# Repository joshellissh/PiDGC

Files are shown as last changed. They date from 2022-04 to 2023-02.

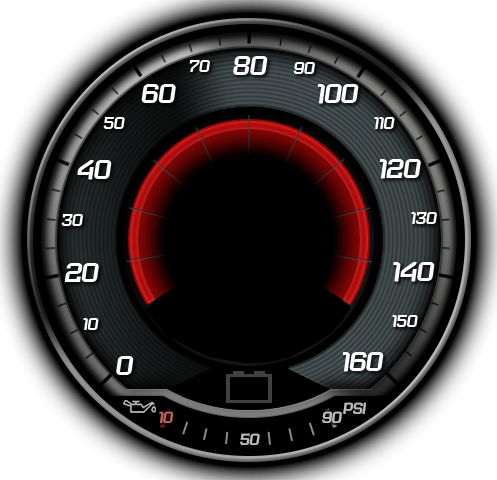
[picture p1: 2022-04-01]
source/display/images/right_gauge_bg_2.png

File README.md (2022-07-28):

# PiDGC v2
Raspberry Pi based Digital Gauge Cluster by Josh Ellis / josh@ellis.sh

**Please Note: This library is designed for the Raspberry Pi 3B, a custom built PCB, and a 1280x480 display. It
will look weird on other displays and won't function without those components.**

### Update Information
This repository is a total rewrite of the PiDGC codebase. The kotlin hardware interface has 
been removed, and all code is now in either the microcontroller (Teensy 4.1) or the Qt 
application running on the RPi. These changes were made to simplify the system and significantly 
shorten the boot time.

### Acknowledgements
In order to reduce the boot time significantly, this version of the gauge cluster uses [buildroot](https://buildroot.org/).
A fork of the [configuration](https://github.com/furkantokac/buildroot) made by [Furkan Tokaç](https://furkantokac.com/rpi3-fast-boot-less-than-2-seconds/) 
is the basis of this build, so many thanks for the reduced boot time go to him! Please go and check out his work, 
it's great.

### Software Steps
Since this is a buildroot build and no binaries are provided, you must build the image for the Raspberry Pi 3 yourself.
This isn't a complicated process, but does require either a Linux system or WSL2.

**These are high level steps only. If you have questions about how to do any step, please Google it.**

1. `cd` into the `buildroot` directory
2. `make pidgc_defconfig`
3. `make -j8`
4. `./build-rpi3-qt.sh`
5. Setup Qt Creator to use the qmake found in `buildroot/output/qt/qt-everywhere-src-*/aaaout/bin/qmake` and compile for the Raspberyr Pi 3.
6. Open `source/display` in Qt Creator and compile for RPi3.
7. Run `make -j8` again. This should pull in the `rpi3-display/display` binary and create the `sdcard.img` in `buildroot/output/images/sdcard.img`.
8. Burn the image file to a micro SD card.
9. All done!

### Custom PCB
The PCB was designed in EAGLE, and is located in `files/PiDGCv2-pcb`

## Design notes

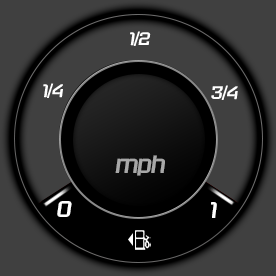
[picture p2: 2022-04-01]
source/display/images/right_gauge_fg.png

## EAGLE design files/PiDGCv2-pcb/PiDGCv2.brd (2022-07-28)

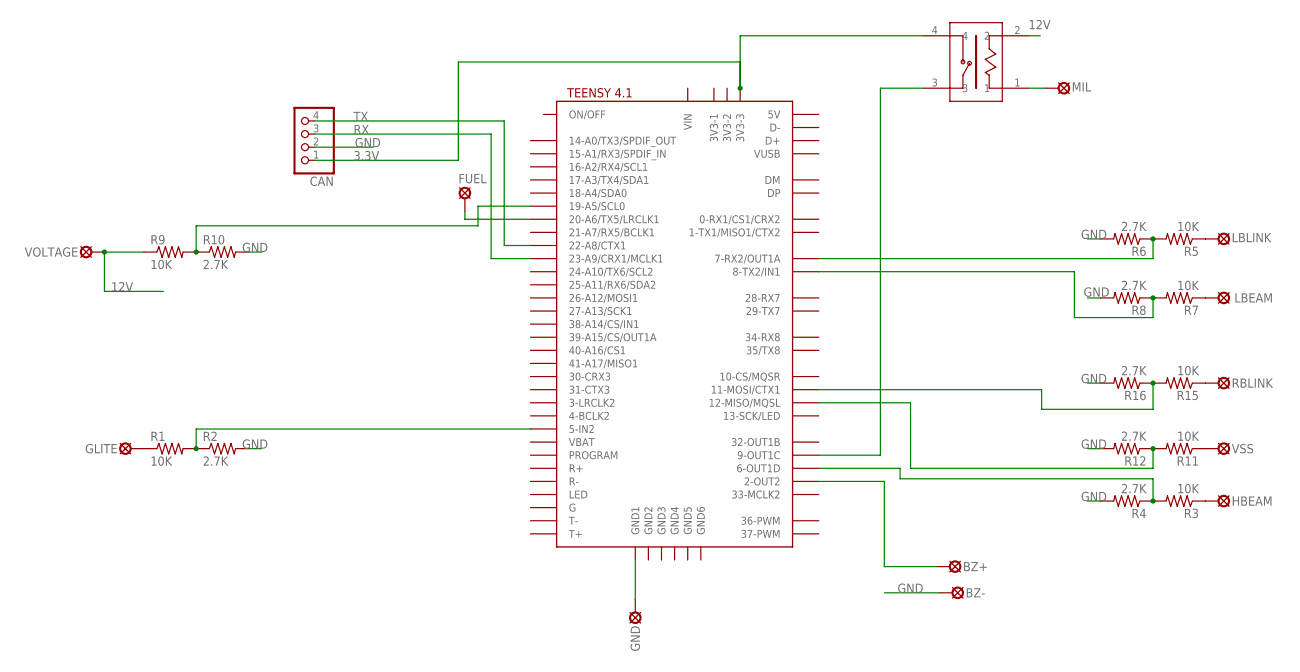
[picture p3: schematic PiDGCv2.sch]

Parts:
BZ+: LSP10
BZ-: LSP10
CAN: PINHD-1X4; 1X04
FUEL: LSP10
GLITE: LSP10
GND: LSP10
HBEAM: LSP10
LBEAM: LSP10
LBLINK: LSP10
MIL: LSP10
MIL_RELAY: BR-1050-VP; RELAY
R1, R3, R5, R7, R9, R11, R15: 10K; 0204/7
R2, R4, R6, R8, R10, R12, R16: 2.7K; 0204/7
RBLINK: LSP10
U$1: TEENSY41
VOLTAGE: LSP10
VSS: LSP10

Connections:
3.3V: CAN.1, MIL_RELAY.4, U$1.3V3-3
12V: MIL_RELAY.2, R9.1, VOLTAGE.MP; also elsewhere on the board
GND: BZ-.MP, CAN.2, GND.MP, R2.2, R4.2, R6.2, R8.2, R10.2, R12.2, R16.2, U$1.GND1
unnamed: R3.2, R4.1, U$1.6-OUT1D
unnamed: R1.2, R2.1, U$1.5-IN2
unnamed: GLITE.MP, R1.1
unnamed: HBEAM.MP, R3.1
unnamed: R5.2, R6.1, U$1.7-RX2/OUT1A
unnamed: LBLINK.MP, R5.1
unnamed: R7.2, R8.1, U$1.8-TX2/IN2 (8-TX2/IN1)
unnamed: LBEAM.MP, R7.1
unnamed: FUEL.MP, U$1.20-A6/TX5/LRCLK1
unnamed: R9.2, R10.1, U$1.19-A5/SCL0
unnamed: R11.2, R12.1, U$1.12-MISO/MQSL
unnamed: R11.1, VSS.MP
unnamed: R15.2, R16.1, U$1.11-MOSI/CTX1
unnamed: R15.1, RBLINK.MP
unnamed: MIL.MP, MIL_RELAY.1
unnamed: MIL_RELAY.3, U$1.9-OUT1C
unnamed: BZ+.MP, U$1.2-OUT2
RX: CAN.3, U$1.23-A9/CRX1/MCLK1
TX: CAN.4, U$1.22-A8/CTX1

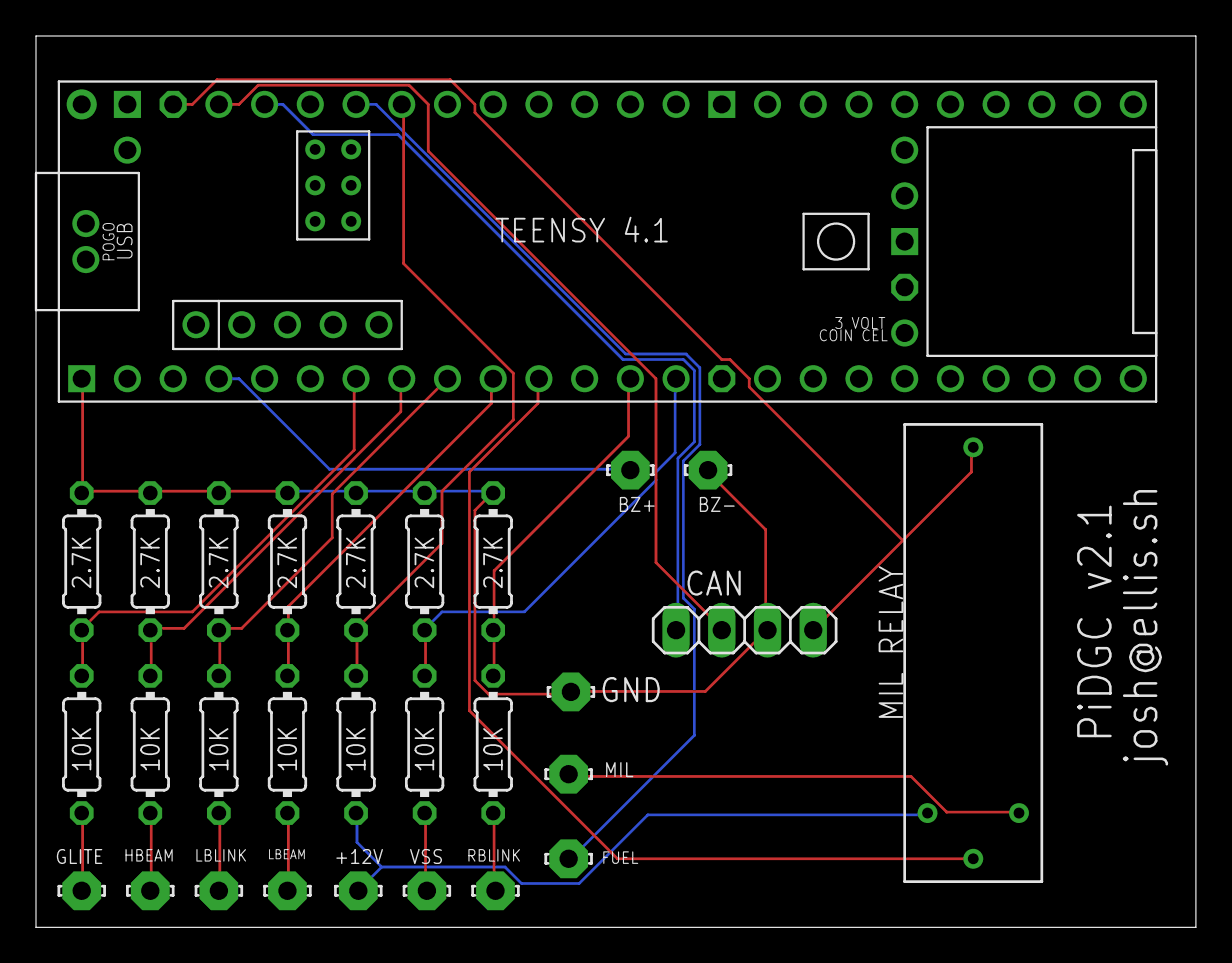
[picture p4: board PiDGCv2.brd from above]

Board: 2 copper layers, 64.4 x 49.5 mm, 29 parts (0 on the bottom side), 22 nets.

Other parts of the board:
+12V: LSP10

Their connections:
12V: +12V.MP; also elsewhere on the board

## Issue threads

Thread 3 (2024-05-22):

Stuck on make -j8 command

Hanifudin95, 2024-05-22:
hello josh, currently i am stuck on make -j8 command. What should i do mate

make -j8
>>>   Finalizing target directory
# Check files that are touched by more than one package
./support/scripts/check-uniq-files -t target /home/pi/PiDGC/buildroot/output/build/packages-file-list.txt
./support/scripts/check-uniq-files -t staging /home/pi/PiDGC/buildroot/output/build/packages-file-list-staging.txt
./support/scripts/check-uniq-files -t host /home/pi/PiDGC/buildroot/output/build/packages-file-list-host.txt
Warning: host file "./lib/gcc/arm-buildroot-linux-gnueabihf/7.4.0/plugin/include/realmpfr.h" is touched by more than one package: [u'host-gcc-initial', u'host-gcc-final']
Warning: host file "./lib/gcc/arm-buildroot-linux-gnueabihf/7.4.0/plugin/include/pretty-print.h" is touched by more than one package: [u'host-gcc-initial', u'host-gcc-final']
Warning: host file "./lib/gcc/arm-buildroot-linux-gnueabihf/7.4.0/plugin/include/tree-ssa-alias.h" is touched by more than one package: [u'host-gcc-initial', u'host-gcc-final']
Warning: host file "./lib/gcc/arm-buildroot-linux-gnueabihf/7.4.0/plugin/include/dojump.h" is touched by more than one package: [u'host-gcc-initial', u'host-gcc-final']
Warning: host file "./lib/gcc/arm-buildroot-linux-gnueabihf/7.4.0/plugin/include/params.h" is touched by more than one package: [u'host-gcc-initial', u'host-gcc-final']
Warning: host file "./lib/gcc/arm-buildroot-linux-gnueabihf/7.4.0/plugin/include/attribs.h" is touched by more than one package: [u'host-gcc-initial', u'host-gcc-final']
Warning: host file "./lib/gcc/arm-buildroot-linux-gnueabihf/7.4.0/plugin/include/tree-ssa-scopedtables.h" is touched by more than one package: [u'host-gcc-initial', u'host-gcc-final']
Warning: host file "./lib/gcc/arm-buildroot-linux-gnueabihf/7.4.0/include/stddef.h" is touched by more than one package: [u'host-gcc-initial', u'host-gcc-final']
Warning: host file "./lib/gcc/arm-buildroot-linux-gnueabihf/7.4.0/plugin/include/tree-affine.h" is touched by more than one package: [u'host-gcc-initial', u'host-gcc-final']
Warning: host file "./bin/arm-buildroot-linux-gnueabihf-gcc.br_real" is touched by more than one package: [u'host-gcc-initial', u'host-gcc-final']
Warning: host file "./libexec/gcc/arm-buildroot-linux-gnueabihf/7.4.0/liblto_plugin.so.0.0.0" is touched by more than one package: [u'host-gcc-initial', u'host-gcc-final']
Warning: host file "./lib/gcc/arm-buildroot-linux-gnueabihf/7.4.0/plugin/include/rtl-error.h" is touched by more than one package: [u'host-gcc-initial', u'host-gcc-final']
Warning: host file "./lib/gcc/arm-buildroot-linux-gnueabihf/7.4.0/plugin/include/tree-ssa-threadedge.h" is touched by more than one package: [u'host-gcc-initial', u'host-gcc-final']
Warning: host file "./lib/gcc/arm-buildroot-linux-gnueabihf/7.4.0/plugin/include/cfg-flags.def" is touched by more than one package: [u'host-gcc-initial', u'host-gcc-final']
Warning: host file "./lib/gcc/arm-buildroot-linux-gnueabihf/7.4.0/plugin/include/pass-instances.def" is touched by more than one package: [u'host-gcc-initial', u'host-gcc-final']
Warning: host file "./lib/gcc/arm-buildroot-linux-gnueabihf/7.4.0/plugin/include/params-options.h" is touched by more than one package: [u'host-gcc-initial', u'host-gcc-final']
Warning: host file "./lib/gcc/arm-buildroot-linux-gnueabihf/7.4.0/plugin/include/alias.h" is touched by more than one package: [u'host-gcc-initial', u'host-gcc-final']
Warning: host file "./lib/gcc/arm-buildroot-linux-gnueabihf/7.4.0/plugin/include/rtlhash.h" is touched by more than one package: [u'host-gcc-initial', u'host-gcc-final']
Warning: host file "./lib/gcc/arm-buildroot-linux-gnueabihf/7.4.0/plugin/include/tree-vrp.h" is touched by more than one package: [u'host-gcc-initial', u'host-gcc-final']
Warning: host file "./lib/gcc/arm-buildroot-linux-gnueabihf/7.4.0/plugin/include/calls.h" is touched by more than one package: [u'host-gcc-initial', u'host-gcc-final']
Warning: host file "./lib/gcc/arm-buildroot-linux-gnueabihf/7.4.0/install-tools/mkheaders.conf" is touched by more than one package: [u'host-gcc-initial', u'host-gcc-final']
Warning: host file "./lib/gcc/arm-buildroot-linux-gnueabihf/7.4.0/plugin/include/tree-chrec.h" is touched by more than one package: [u'host-gcc-initial', u'host-gcc-final']
Warning: host file "./lib/gcc/arm-buildroot-linux-gnueabihf/7.4.0/plugin/include/cilkplus.def" is touched by more than one package: [u'host-gcc-initial', u'host-gcc-final']
Warning: host file "./lib/gcc/arm-buildroot-linux-gnueabihf/7.4.0/plugin/include/cif-code.def" is touched by more than one package: [u'host-gcc-initial', u'host-gcc-final']
Warning: host file "./lib/gcc/arm-buildroot-linux-gnueabihf/7.4.0/plugin/include/hard-reg-set.h" is touched by more than one package: [u'host-gcc-initial', u'host-gcc-final']
Warning: host file "./lib/gcc/arm-buildroot-linux-gnueabihf/7.4.0/plugin/include/substring-locations.h" is touched by more than one package: [u'host-gcc-initial', u'host-gcc-final']
Warning: host file "./bin/arm-linux-gcc-ranlib" is touched by more than one package: [u'host-gcc-initial', u'host-gcc-final']
Warning: host file "./lib/gcc/arm-buildroot-linux-gnueabihf/7.4.0/plugin/include/input.h" is touched by more than one package: [u'host-gcc-initial', u'host-gcc-final']
Warning: host file "./lib/gcc/arm-buildroot-linux-gnueabihf/7.4.0/plugin/include/gcc-symtab.h" is touched by more than one package: [u'host-gcc-initial', u'host-gcc-final']
Warning: host file "./lib/gcc/arm-buildroot-linux-gnueabihf/7.4.0/plugin/include/optabs.def" is touched by more than one package: [u'host-gcc-initial', u'host-gcc-final']
Warning: host file "./lib/gcc/arm-buildroot-linux-gnueabihf/7.4.0/plugin/include/tree-iterator.h" is touched by more than one package: [u'host-gcc-initial', u'host-gcc-final']
Warning: host file "./lib/gcc/arm-buildroot-linux-gnueabihf/7.4.0/plugin/include/tree-outof-ssa.h" is touched by more than one package: [u'host-gcc-initial', u'host-gcc-final']
Warning: host file "./lib/gcc/arm-buildroot-linux-gnueabihf/7.4.0/plugin/include/streamer-hooks.h" is touched by more than one package: [u'host-gcc-initial', u'host-gcc-final']
Warning: host file "./lib/gcc/arm-buildroot-linux-gnueabihf/7.4.0/plugin/include/symbol-summary.h" is touched by more than one package: [u'host-gcc-initial', u'host-gcc-final']
Warning: host file "./lib/gcc/arm-buildroot-linux-gnueabihf/7.4.0/plugin/include/ccmp.h" is touched by more than one package: [u'host-gcc-initial', u'host-gcc-final']
Warning: host file "./lib/gcc/arm-buildroot-linux-gnueabihf/7.4.0/install-tools/macro_list" is touched by more than one package: [u'host-gcc-initial', u'host-gcc-final']
Warning: host file "./lib/gcc/arm-buildroot-linux-gnueabihf/7.4.0/plugin/include/stor-layout.h" is touched by more than one package: [u'host-gcc-initial', u'host-gcc-final']
Warning: host file "./lib/gcc/arm-buildroot-linux-gnueabihf/7.4.0/plugin/include/auto-profile.h" is touched by more than one package: [u'host-gcc-initial', u'host-gcc-final']
Warning: host file "./lib/gcc/arm-buildroot-linux-gnueabihf/7.4.0/plugin/include/trans-mem.h" is touched by more than one package: [u'host-gcc-initial', u'host-gcc-final']
Warning: host file "./lib/gcc/arm-buildroot-linux-gnueabihf/7.4.0/plugin/include/cfghooks.h" is touched by more than one package: [u'host-gcc-initial', u'host-gcc-final']
Warning: host file "./lib/gcc/arm-buildroot-linux-gnueabihf/7.4.0/plugin/include/ggc.h" is touched by more than one package: [u'host-gcc-initial', u'host-gcc-final']
Warning: host file "./lib/gcc/arm-buildroot-linux-gnueabihf/7.4.0/plugin/include/lra.h" is touched by more than one package: [u'host-gcc-initial', u'host-gcc-final']
Warning: host file "./lib/gcc/arm-buildroot-linux-gnueabihf/7.4.0/plugin/include/config/arm/arm-opts.h" is touched by more than one package: [u'host-gcc-initial', u'host-gcc-final']
Warning: host file "./bin/arm-linux-gcc-7.4.0" is touched by more than one package: [u'host-gcc-initial', u'host-gcc-final']
Warning: host file "./lib/gcc/arm-buildroot-linux-gnueabihf/7.4.0/plugin/include/fixed-value.h" is touched by more than one package: [u'host-gcc-initial', u'host-gcc-final']
Warning: host file "./lib/gcc/arm-buildroot-linux-gnueabihf/7.4.0/plugin/include/sbitmap.h" is touched by more than one package: [u'host-gcc-initial', u'host-gcc-final']
Warning: host file "./lib/gcc/arm-buildroot-linux-gnueabihf/7.4.0/plugin/include/explow.h" is touched by more than one package: [u'host-gcc-initial', u'host-gcc-final']
Warning: host file "./share/man/man7/fsf-funding.7" is touched by more than one package: [u'host-gcc-initial', u'host-gcc-final']
Warning: host file "./lib/gcc/arm-buildroot-linux-gnueabihf/7.4.0/plugin/include/profile.h" is touched by more than one package: [u'host-gcc-initial', u'host-gcc-final']
Warning: host file "./lib/gcc/arm-buildroot-linux-gnueabihf/7.4.0/plugin/include/et-forest.h" is touched by more than one package: [u'host-gcc-initial', u'host-gcc-final']
Warning: host file "./lib/gcc/arm-buildroot-linux-gnueabihf/7.4.0/plugin/include/cfgrtl.h" is touched by more than one package: [u'host-gcc-initial', u'host-gcc-final']
Warning: host file "./lib/gcc/arm-buildroot-linux-gnueabihf/7.4.0/plugin/include/mem-stats-traits.h" is touched by more than one package: [u'host-gcc-initial', u'host-gcc-final']
Warning: host file "./lib/gcc/arm-buildroot-linux-gnueabihf/7.4.0/plugin/include/config/linux-android.h" is touched by more than one package: [u'host-gcc-initial', u'host-gcc-final']
Warning: host file "./share/info/dir" is touched by more than one package: [u'host-tar', u'host-m4', u'host-bison', u'host-gawk', u'host-binutils', u'host-gmp', u'host-mpfr', u'host-mpc', u'host-gcc-final', u'host-autoconf', u'host-automake', u'host-gettext']
Warning: host file "./libexec/gcc/arm-buildroot-linux-gnueabihf/7.4.0/lto1" is touched by more than one package: [u'host-gcc-initial', u'host-gcc-final']
Warning: host file "./lib/gcc/arm-buildroot-linux-gnueabihf/7.4.0/plugin/include/predict.h" is touched by more than one package: [u'host-gcc-initial', u'host-gcc-final']
Warning: host file "./lib/gcc/arm-buildroot-linux-gnueabihf/7.4.0/plugin/include/domwalk.h" is touched by more than one package: [u'host-gcc-initial', u'host-gcc-final']
Warning: host file "./lib/gcc/arm-buildroot-linux-gnueabihf/7.4.0/plugin/include/gimple-pretty-print.h" is touched by more than one package: [u'host-gcc-initial', u'host-gcc-final']
Warning: host file "./lib/gcc/arm-buildroot-linux-gnueabihf/7.4.0/include/stdfix.h" is touched by more than one package: [u'host-gcc-initial', u'host-gcc-final']
Warning: host file "./lib/gcc/arm-buildroot-linux-gnueabihf/7.4.0/plugin/include/tree-pretty-print.h" is touched by more than one package: [u'host-gcc-initial', u'host-gcc-final']
Warning: host file "./lib/gcc/arm-buildroot-linux-gnueabihf/7.4.0/include/arm_acle.h" is touched by more than one package: [u'host-gcc-initial', u'host-gcc-final']
Warning: host file "./lib/gcc/arm-buildroot-linux-gnueabihf/7.4.0/plugin/include/tree-ssa-sccvn.h" is touched by more than one package: [u'host-gcc-initial', u'host-gcc-final']
Warning: host file "./lib/gcc/arm-buildroot-linux-gnueabihf/7.4.0/plugin/include/tree-cfgcleanup.h" is touched by more than one package: [u'host-gcc-initial', u'host-gcc-final']
Warning: host file "./lib/gcc/arm-buildroot-linux-gnueabihf/7.4.0/plugin/include/builtin-types.def" is touched by more than one package: [u'host-gcc-initial', u'host-gcc-final']
Warning: host file "./bin/arm-linux-ld.bfd" is touched by more than one package: [u'host-gcc-initial', u'host-gcc-final']
Warning: host file "./lib/gcc/arm-buildroot-linux-gnueabihf/7.4.0/plugin/include/ipa-icf.h" is touched by more than one package: [u'host-gcc-initial', u'host-gcc-final']
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

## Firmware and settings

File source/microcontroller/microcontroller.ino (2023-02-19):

#define NO_PULSE    99999
#define LOW_FREQ    5000000   // 5s
#define MED_FREQ    250000    // 250ms
#define HI_FREQ     100000    // 100ms

#include "pins.h"
#include "sdcard.h"
#include "values.h"
#include "serialreader.h"
#include "serialComms.h"
#include "analogReaders.h"
#include "canbus.h"
#include "buzzerSound.h"
#include "patternBuzzer.h"
#include "indicators.h"
#include "datalogger.h"

SDCard sdCard;
Values values;
Indicators indicators;
FlexCAN_T4<CAN1, RX_SIZE_256, TX_SIZE_16> can1;
BuzzerSound blinkerSound(BUZZER, 50);
BuzzerSound milSound(BUZZER, 3000, 30000);
PatternBuzzer fuelBuzzer(BUZZER, (unsigned int []){1,1,1,1,0,1,1,1,1}, 9, 250, 750, 600000);
PatternBuzzer gaugeLiteBuzzer(BUZZER, (unsigned int []){1,1,0}, 3, 250, 750, 3000);

USBHost usbHost;
USBHub usbHub(usbHost);
USBDrive usbDrive(usbHost);
USBFilesystem usbFS(usbHost);
DataLogger dataLogger;

void setup() {
  // Turn on LED as a power indicator
  pinMode(13, OUTPUT);
  digitalWrite(13, HIGH);

  // High priority logging switch & LED
  pinMode(HPL_LED, OUTPUT);
  pinMode(HPL_INPUT, INPUT);

  // Initialize serial
  Serial.begin(115200);

  // Initialize SD card systems
  sdCard.initCard();

  // Configure CAN bus
  canInit();

  // Initialize datalogger
  dataLogger.init();

  // Initialize smoothed variables
  values.fuelLevel.begin(SMOOTHED_AVERAGE, 100);
  values.mph.begin(SMOOTHED_AVERAGE, 20);
  values.voltage.begin(SMOOTHED_AVERAGE, 20);

  // Set value to expiration so it will fire immediately on boot
  values.lowFrequency = LOW_FREQ;

  // Set pin modes
  pinMode(VSS, INPUT_PULLUP);
  attachInterrupt(VSS, vssInterrupt, RISING);
  pinMode(HIGH_BEAMS, INPUT);
  pinMode(LOW_BEAMS, INPUT);
  pinMode(RIGHT_BLINKER, INPUT);
  pinMode(LEFT_BLINKER, INPUT);
  pinMode(MIL, INPUT_PULLDOWN);
  pinMode(GAUGE_LIGHTS, INPUT);

  // Load initial values from files
  values.tripOdometer = sdCard.readFloat(TRIP_FILE, 0.0f);
  values.odometer = sdCard.readFloat(ODOMETER_FILE, 0.0f);
  values.ppm = sdCard.readInt(PPM_FILE, 10500);
  values.blinkerSound = sdCard.readBool(BLINKER_FILE, true);
  values.screenDimming = sdCard.readInt(DIMMING_FILE, 20); 
}

void loop() {
  handleComms(sdCard, values);
  indicators.update(milSound);

  // Process necessary canbus events
  can1.events();

  // process buzzer sounds
  blinkerSound.loop();
  milSound.loop();
  fuelBuzzer.loop();
  gaugeLiteBuzzer.loop();

  // High frequency updates
  if (values.highFrequency >= HI_FREQ) {
    values.highFrequency -= HI_FREQ;

    // Request engine RPM
    canSendOBD2(0x0C);

    // Request MAP
    canSendOBD2(0x0B);

    // Request IAT
    canSendOBD2(0x0F);
    
    // Request Timing Advance
    canSendOBD2(0x0E);
    
    // Request Throttle Position (Relative)
    canSendOBD2(0x45);

    // Request Foot Pedal Position (Relative)
    canSendOBD2(0x5A);

    // Request Oxygen Sensor 1 - Air-Fuel Equivalence Ratio
    canSendOBD2(0x34);

    // Request Short Term Fuel Trim - Bank 1
    canSendOBD2(0x06);

    // Request Long Term Fuel Trim - Bank 1
    canSendOBD2(0x07);

    // Request Throttle Inlet Pressure
    canSendOBD2(0x70);

    // Request Fuel Rail Pressure
    canSendOBD2(0x23);

    cli();
    unsigned int numPulses = values.vssPulseCounter;
    unsigned int pulseSepMicros = values.vssPulseSeparation;
    sei();
    values.vssPulseCounter = 0;
    values.vssPulseSeparation = NO_PULSE;

    // Pulses counted / pulses per mile = distance travelled.
    float distance = (float)numPulses / (float)values.ppm;

    // Update odometers
    values.odometer += distance;
    values.tripOdometer += distance;

    // Write updated odometers to file
    writeOdometers(values.tripOdometer, values.odometer);

    // Update MPH
    if (pulseSepMicros != NO_PULSE && pulseSepMicros > 0) {
        // Calculate MPH
        float oneMphInMicros = 3600000000.0f / (float)values.ppm;
        float mph = oneMphInMicros / (float)pulseSepMicros;
        values.mph.add(mph);
    } else {
        values.mph.add(0.0);
    }

    // Send speed to ECU
    canSendSpeedMPH(values.mph.get());

    {
      // Update blinkers
      readAnalogPins();
  
      bool prevLeftBlinker = values.leftBlinker;
      bool prevRightBlinker = values.rightBlinker;
  
      values.leftBlinker = readLeftBlinker();
      values.rightBlinker = readRightBlinker();
  
      if (values.blinkerSound) {
        if ((!prevLeftBlinker && values.leftBlinker) || (!prevRightBlinker && values.rightBlinker)) {
          blinkerSound.play();
        }
      }
    }

    // Write to data log
    bool hplInput = digitalRead(HPL_INPUT);
    digitalWrite(HPL_LED, hplInput);
    dataLogger.writeValues(values, hplInput);

    // Send rpm, boost, and blinkers
    char output[256] = {0};
    sprintf(output, "rpm:%d\nboost:%f\nleft:%d\nright:%d", values.rpm, values.boostPressure, values.leftBlinker, values.rightBlinker);
    Serial.println(output);
  }

  // Medium frequency updates
  if (values.mediumFrequency >= MED_FREQ) {
    values.mediumFrequency -= MED_FREQ;

    bool prevMil = values.mil;
    values.mil = readMIL();

    if (!prevMil && values.mil) {
      milSound.play();
    }

    if (readGaugeLights() == true && values.rpm <= 250) {
      gaugeLiteBuzzer.play();
    }

    // Request IAT
    canSendOBD2(0x0F);

    char output[512] = {0};
    sprintf(
      output, 
      "voltage:%f\nfuel:%f\nhi:%d\nlow:%d\nmil:%d\nglite:%d\nmph:%d\noil:%f",
      values.voltage.get(),
      values.fuelLevel.get(),
      readHighBeams(),
      readLowBeams(),
      values.mil,
      readGaugeLights(),
      values.mph.get(),
      values.oilPressure
    );
    Serial.println(output);

    float tripOdometer = sdCard.readFloat(TRIP_FILE, 0.0f);
    float odometer = sdCard.readFloat(ODOMETER_FILE, 0.0f);
    sprintf(output, "odo:%f,%f", tripOdometer, odometer);
    Serial.println(output);
  }

  // Low frequency updates
  if (values.lowFrequency >= LOW_FREQ) {
    values.lowFrequency -= LOW_FREQ;

    // Request coolant temp
    canSendOBD2(0x05);

    // Request Barometric Pressure
    canSendOBD2(0x33);

    char output[256] = {0};
    sprintf(output, "coolant:%d", values.coolantTemp);
    Serial.println(output);

    // Play fuel buzzer if needed
    if (values.fuelLevel.get() <= 0.125) {
      fuelBuzzer.play();
    }
  }
}

void readAnalogPins() {
  values.fuelLevel.add(readFuelLevel());
  values.voltage.add(readVoltage());
}

void vssInterrupt() {
  unsigned long currentPulse = micros();
  
  if (values.vssLastPulse > currentPulse) {
    values.vssLastPulse = currentPulse;
    values.vssPulseSeparation = NO_PULSE;
  } else {
    unsigned long pulseDelta = currentPulse - values.vssLastPulse;
    
    if (pulseDelta <= 500) {
      // Impossibly fast. Throw it out.
      return;
    }
    
    values.vssPulseSeparation = currentPulse - values.vssLastPulse;
    values.vssLastPulse = currentPulse;
  }

  values.vssPulseCounter++;
}

void writeOdometers(float trip, float odometer) {
  char currentTrip[10] = {0};
  char currentOdometer[10] = {0};
  char writeTrip[10] = {0};
  char writeOdometer[10] = {0};
  
  dtostrf(sdCard.readFloat(TRIP_FILE, 0.0f), 0, 1, currentTrip);
  dtostrf(sdCard.readFloat(ODOMETER_FILE, 0.0f), 0, 1, currentOdometer);
  dtostrf(trip, 0, 1, writeTrip);
  dtostrf(odometer, 0, 1, writeOdometer);

  // Only write out value if it has changed by more than a 10th of a mile
  if (trip != 0.0f && strcmp(currentTrip, writeTrip) != 0)
    sdCard.writeValue(TRIP_FILE, trip);

  // Only write out value if it has changed by more than a 10th of a mile
  if (odometer != 0.0f && strcmp(currentOdometer, writeOdometer) != 0)
    sdCard.writeValue(ODOMETER_FILE, odometer);
}

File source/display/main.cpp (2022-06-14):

#include "window.h"
#include <QApplication>
#include <QSurfaceFormat>
#include <QThread>
#include <QProcess>
#include "hwdialog.h"
#include "serialcontroller.h"
#include "indicators.h"

int main(int argc, char *argv[])
{
    QApplication app(argc, argv);

    QProcess::execute("pulseaudio -D");

    // Turn on anti-aliasing
    QSurfaceFormat fmt;
    fmt.setSamples(4);
    QSurfaceFormat::setDefaultFormat(fmt);

    VehicleValues vehicle;
    Indicators indicators;

    // Create window
    Window window(vehicle, indicators);
    window.setCursor(Qt::BlankCursor);
    window.show();

    // Create hardware dialog
    HWDialog hwDialog(vehicle, &window);

    // Store dialog reference in various windows
    window.setHWDialog(hwDialog);

    // Start serial interface
    SerialController serialController(vehicle, indicators);
    serialController.start();

    return app.exec();
}

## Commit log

2022-07-20 Add support for teensy
2022-07-28 Update README and add PCB files
    [PiDGCv2.brd, PiDGCv2.sch]
2023-01-27 Send speed to ECU via canbus
2023-01-27 Update blinker frequency and send correct MPH to ECU
    [microcontroller.ino]
2026-10-31 Update README with video link and PCB design info
    Added a link to a demonstration video and included information about the PCB design location.
